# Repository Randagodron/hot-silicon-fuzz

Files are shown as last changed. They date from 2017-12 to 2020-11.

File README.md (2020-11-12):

# Hot Silicon Fuzz
Re-implementation of the FoxRox Hot Silicon Fuzz.

Full analog fuzz with bias and tone control, silicon transistors, relay true bypass, 1590A enclosure format.

Simulated with LTSpice, designed with Kicad. All simulations and CAD files are provided under creative commons CC-BY-SA 4.0

Companion article (in french) : http://blog.randagodron.eu/index.php?post/2018/02/04/DIY-audio-Hot-Silicon-Fuzz

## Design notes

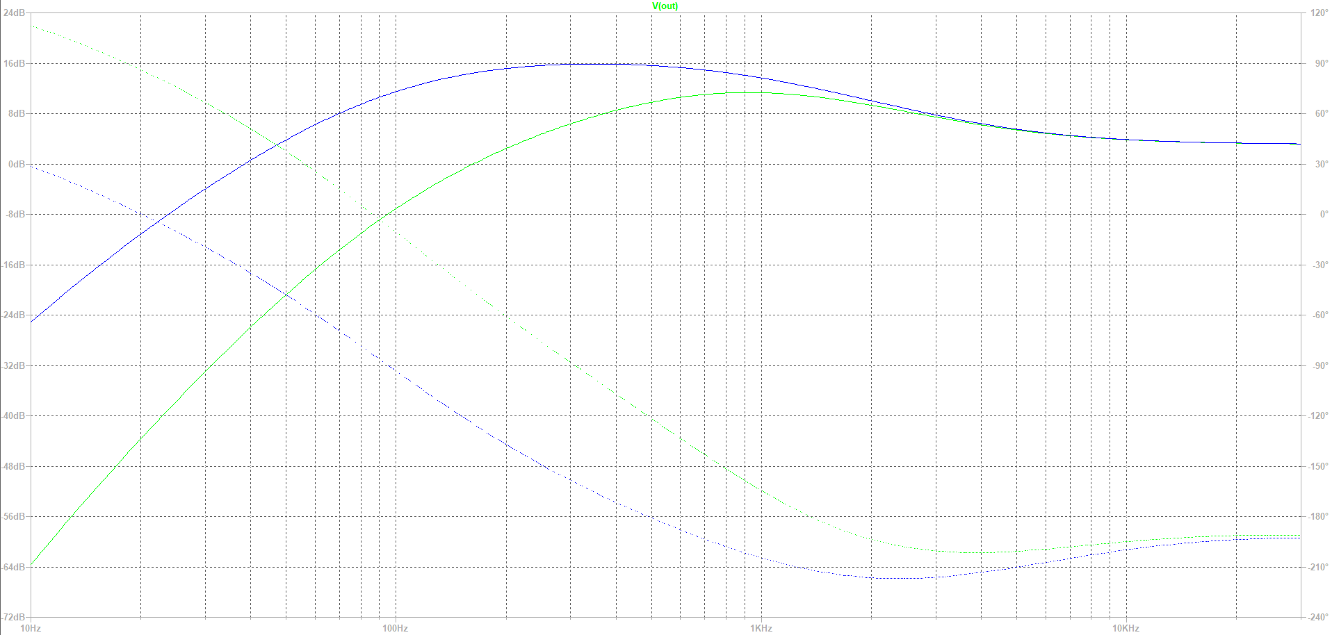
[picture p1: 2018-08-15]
export/sig_03_01_fat.PNG

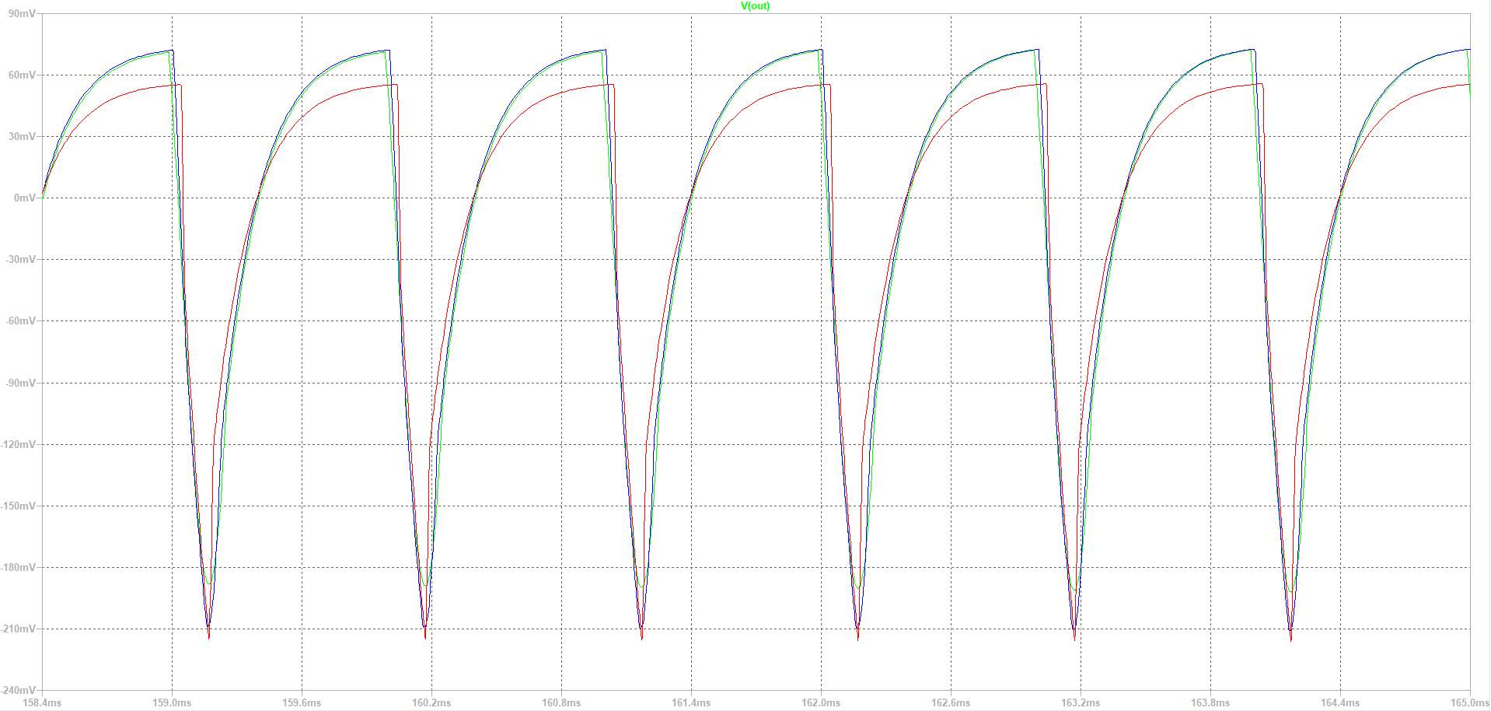
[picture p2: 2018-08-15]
export/sig_04_03.PNG

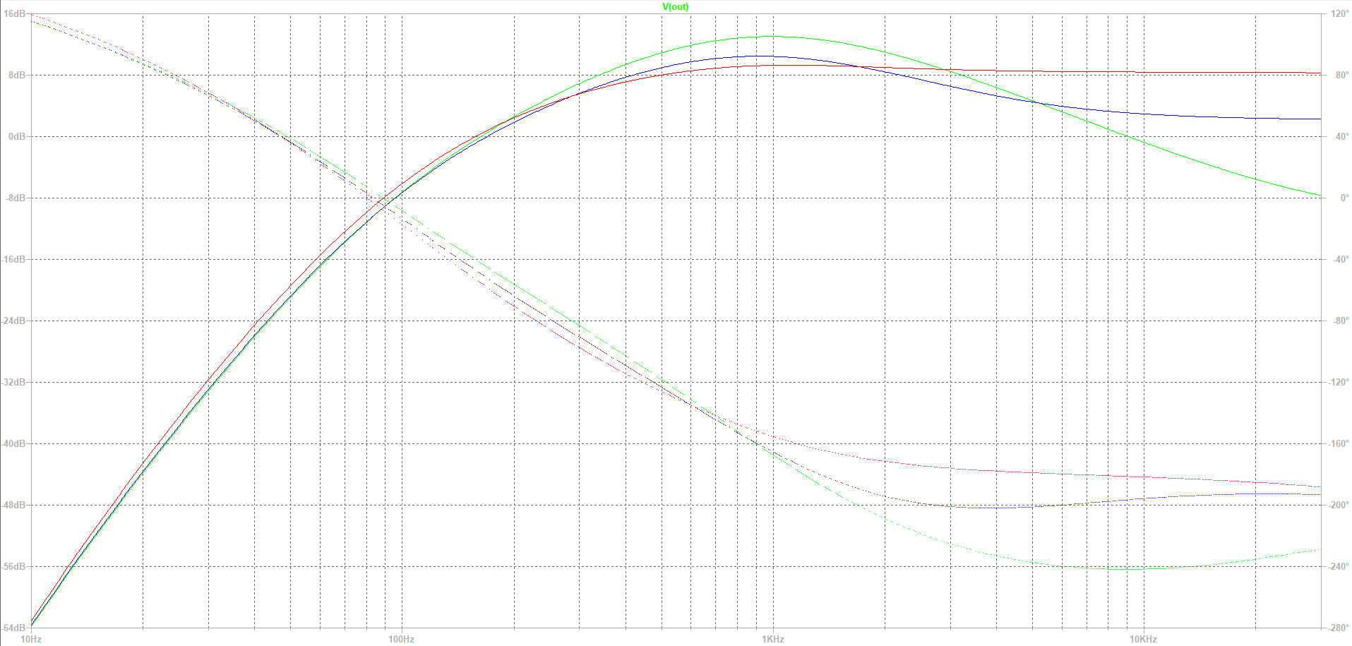
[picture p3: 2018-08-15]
export/sig_03_03_tone_0.PNG

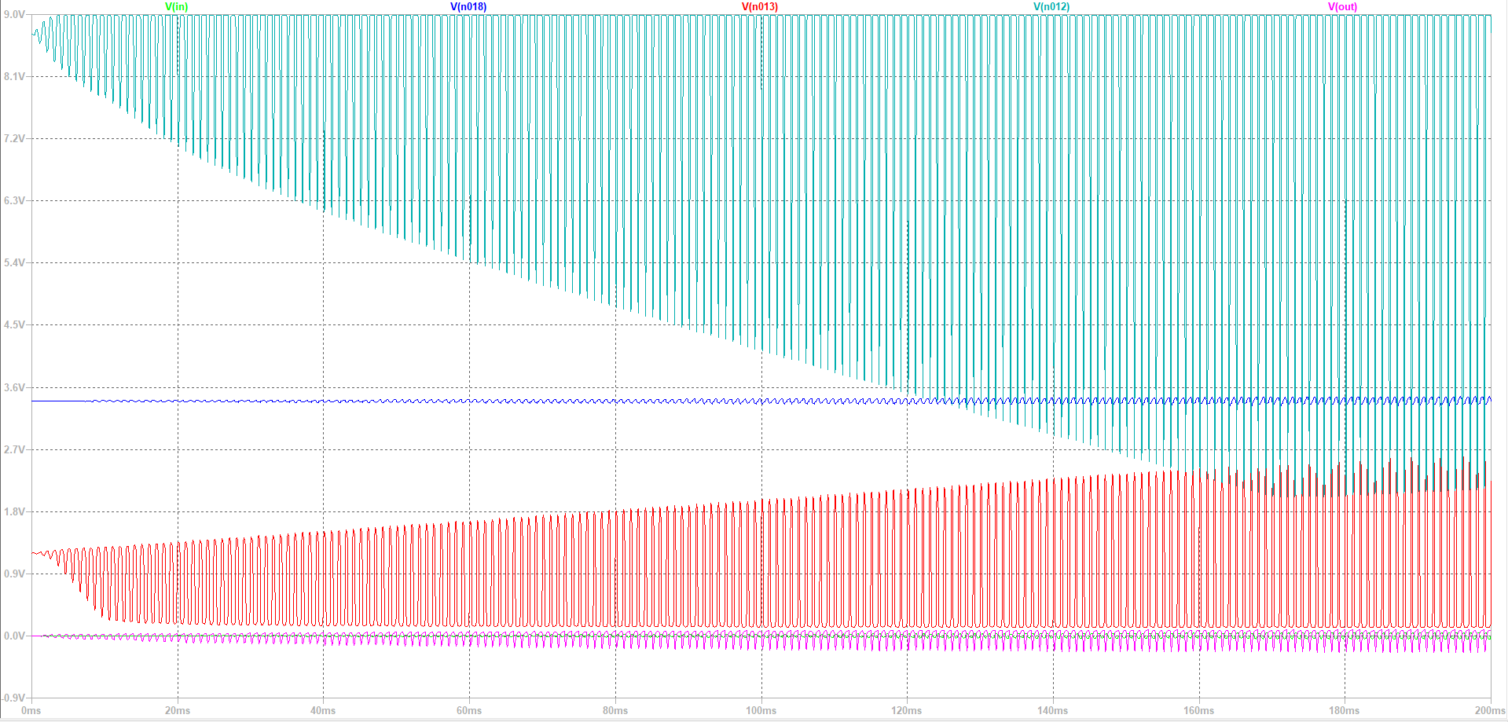
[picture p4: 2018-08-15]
export/sig_02_01_bias0.5.PNG

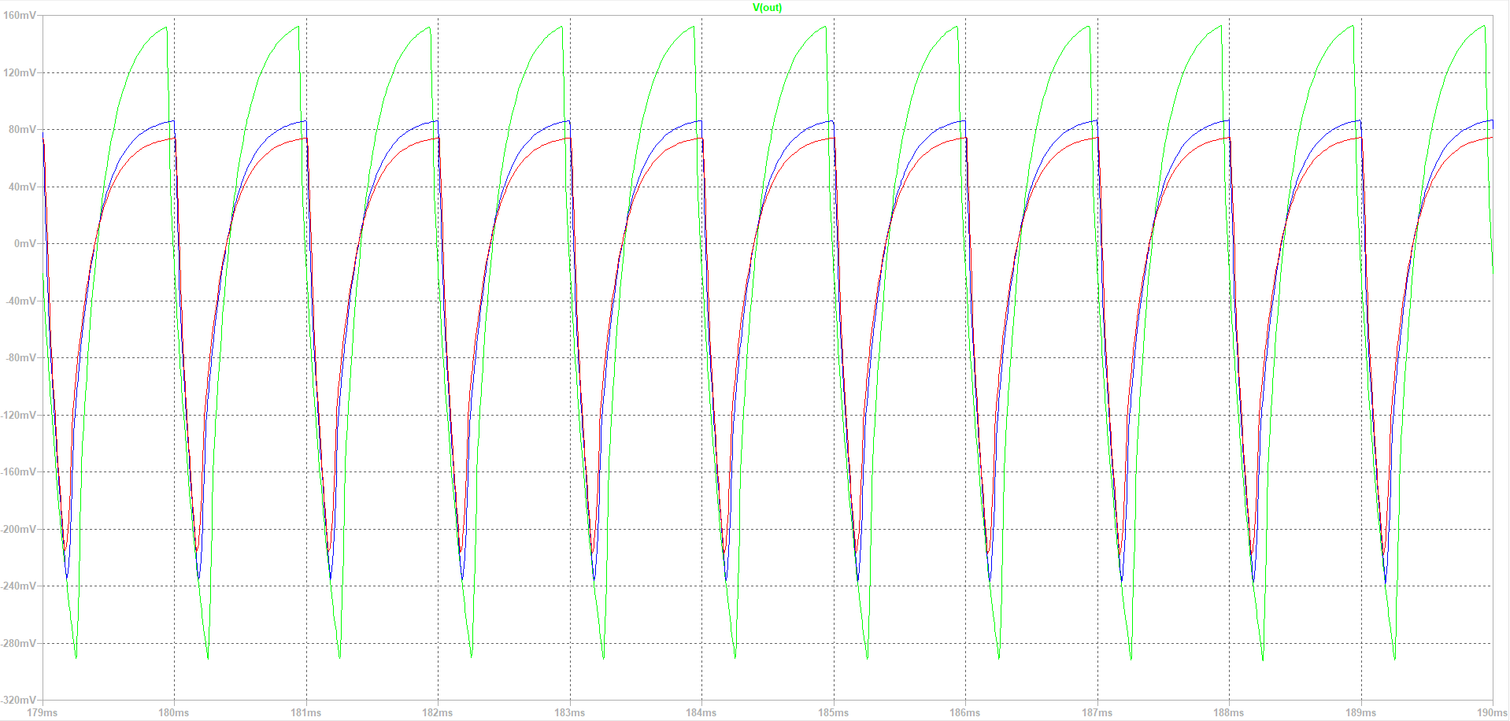
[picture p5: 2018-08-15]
export/sig_02_05.PNG

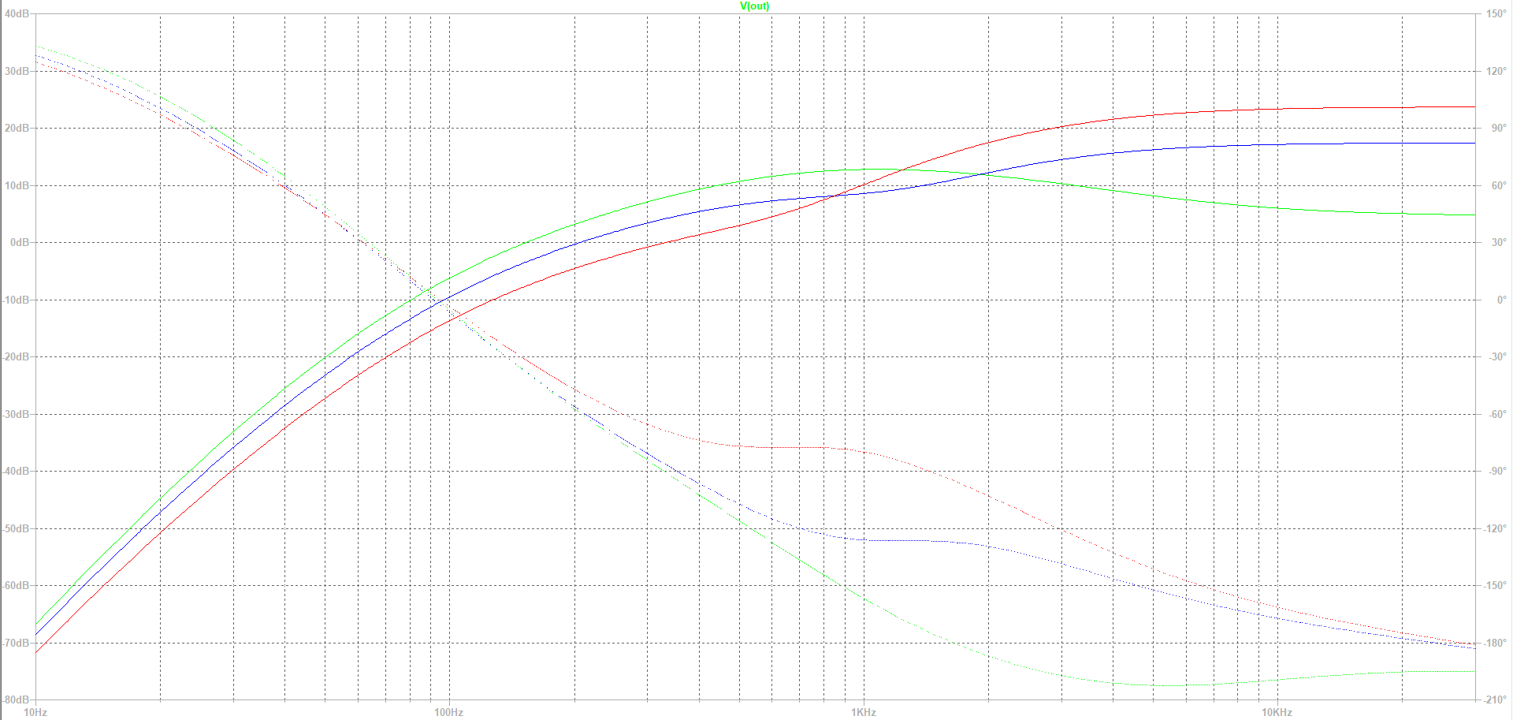
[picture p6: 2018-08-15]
export/sig_03_04_tone_1.PNG

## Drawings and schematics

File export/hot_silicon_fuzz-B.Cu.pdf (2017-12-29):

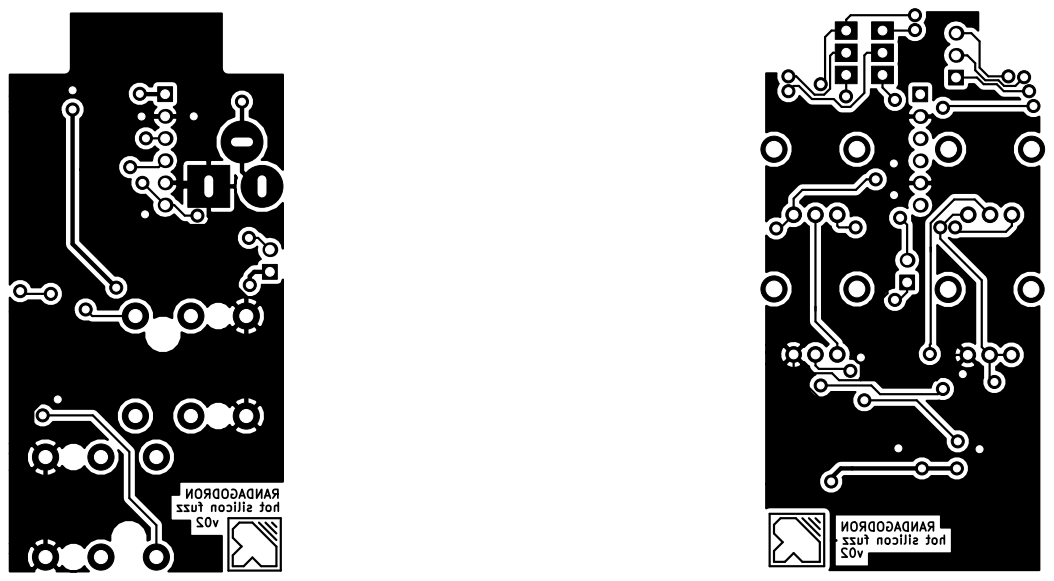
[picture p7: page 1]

v02 hot silicon fuzz v02 RANDAGODRON

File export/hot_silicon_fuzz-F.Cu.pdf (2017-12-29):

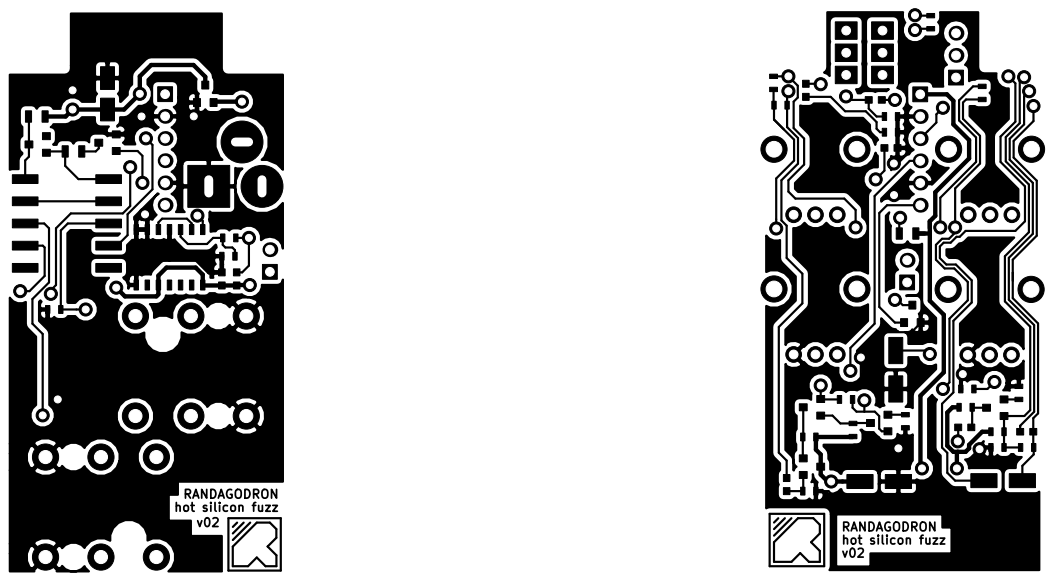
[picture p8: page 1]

v02 hot silicon fuzz RANDAGODRON

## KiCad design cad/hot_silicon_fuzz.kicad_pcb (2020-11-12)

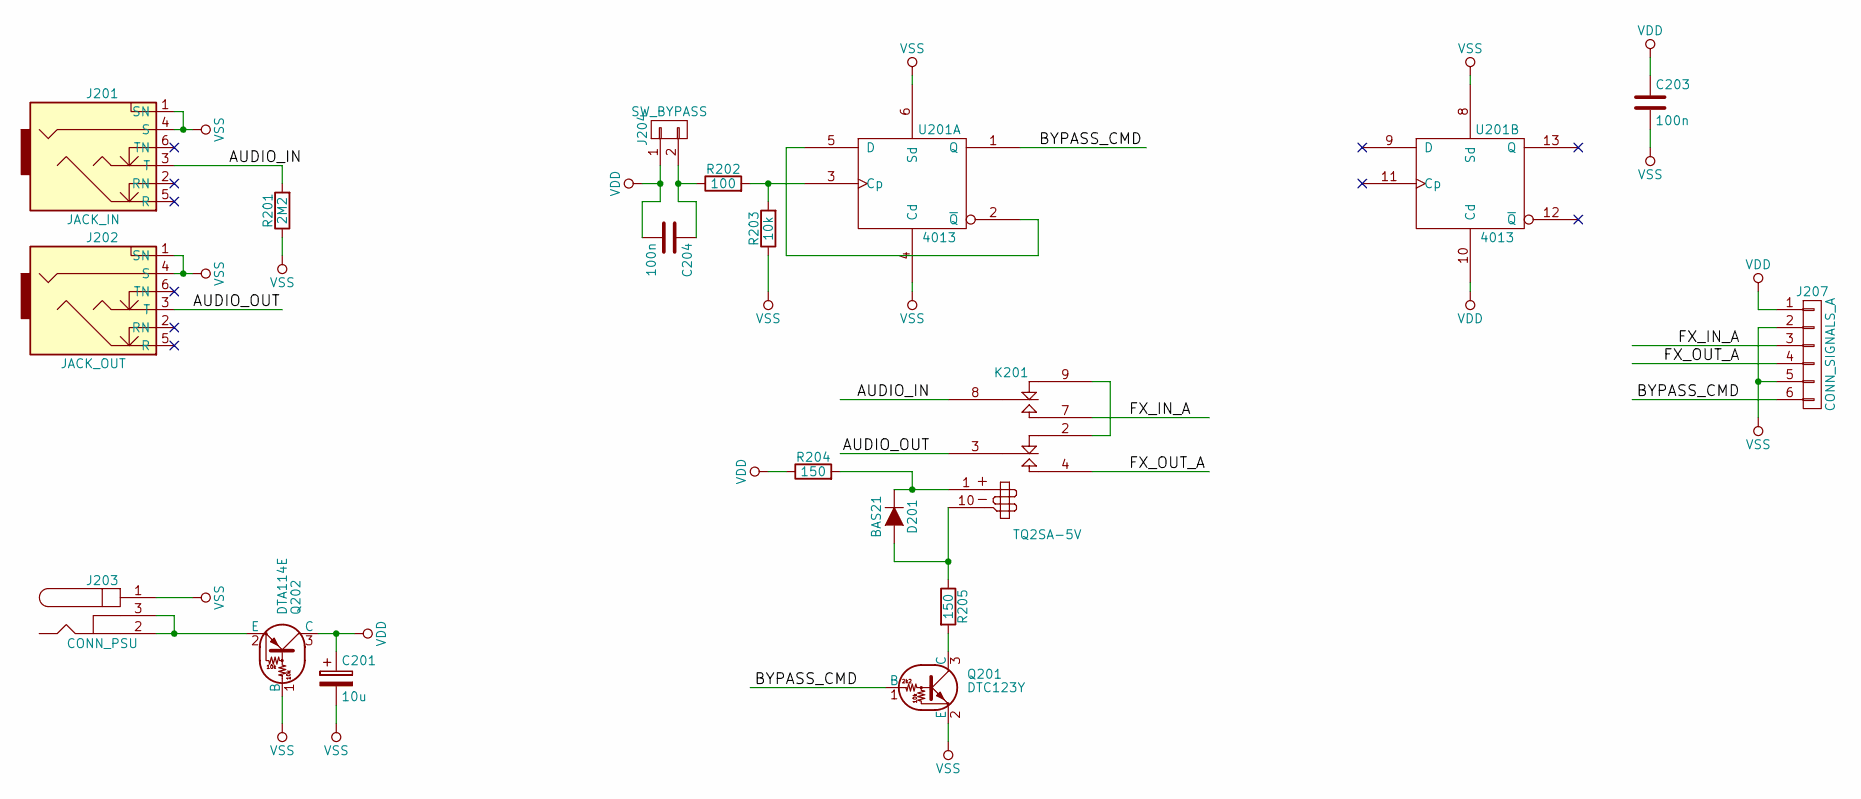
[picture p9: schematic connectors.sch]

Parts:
C201: 10u; CP_Elec_4x4.5
C203, C204: 100n; C_0603
D201: BAS21; SOT-23
J201: JACK_IN; CLIFF_FCR5005x
J202: JACK_OUT; CLIFF_FCR5005x
J203: CONN_PSU; JACK_ALIM
J204: SW_BYPASS; Pin_Header_Straight_1x02_Pitch2.54mm
J207: CONN_SIGNALS_A; Pin_Header_Straight_1x06_Pitch2.54mm
K201: TQ2SA-5V; TQ2SA
Q201: DTC123Y; SOT-23
Q202: DTA114E; SOT-23
R201: 2M2; R_0603
R202: 100; R_0603
R203: 10k; R_0603
R204, R205: 150; R_0805
U201: 4013; SOIC-14_N

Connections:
/CONNECTORS/AUDIO_IN: J201.3 (T), K201.8 (C2), R201.2
/CONNECTORS/AUDIO_OUT: J202.3 (T), K201.3 (C1)
/CONNECTORS/BYPASS_CMD: J207.6, Q201.1 (B), U201.1 (Q)
/CONNECTORS/FX_IN_A: J207.3, K201.7 (T2)
/CONNECTORS/FX_OUT_A: J207.4, K201.4 (T1)
unnamed: C204.1, J204.2, R202.1
unnamed: D201.1 (A), K201.10 (-), R205.1
unnamed: D201.3 (K), K201.1 (+), R204.2
unnamed: J203.2, J203.3, Q202.2 (E)
unnamed: K201.2 (R1), K201.9 (R2)
unnamed: Q201.3 (C), R205.2
unnamed: R202.2, R203.2, U201.3 (Cp)
unnamed: U201.2 (~Q), U201.5 (D)
VDD: C201.1, C203.1, C204.2, J204.1, J207.1, Q202.3 (C), R204.1, U201.10 (Cd), U201.14 (VDD)
VSS: C201.2, C203.2, J201.1 (SN), J201.4 (S), J202.1 (SN), J202.4 (S), J203.1, J207.2, J207.5, Q201.2 (E), Q202.1 (B), R201.1, R203.1, U201.4 (Cd), U201.6 (Sd), U201.7 (VSS), U201.8 (Sd)

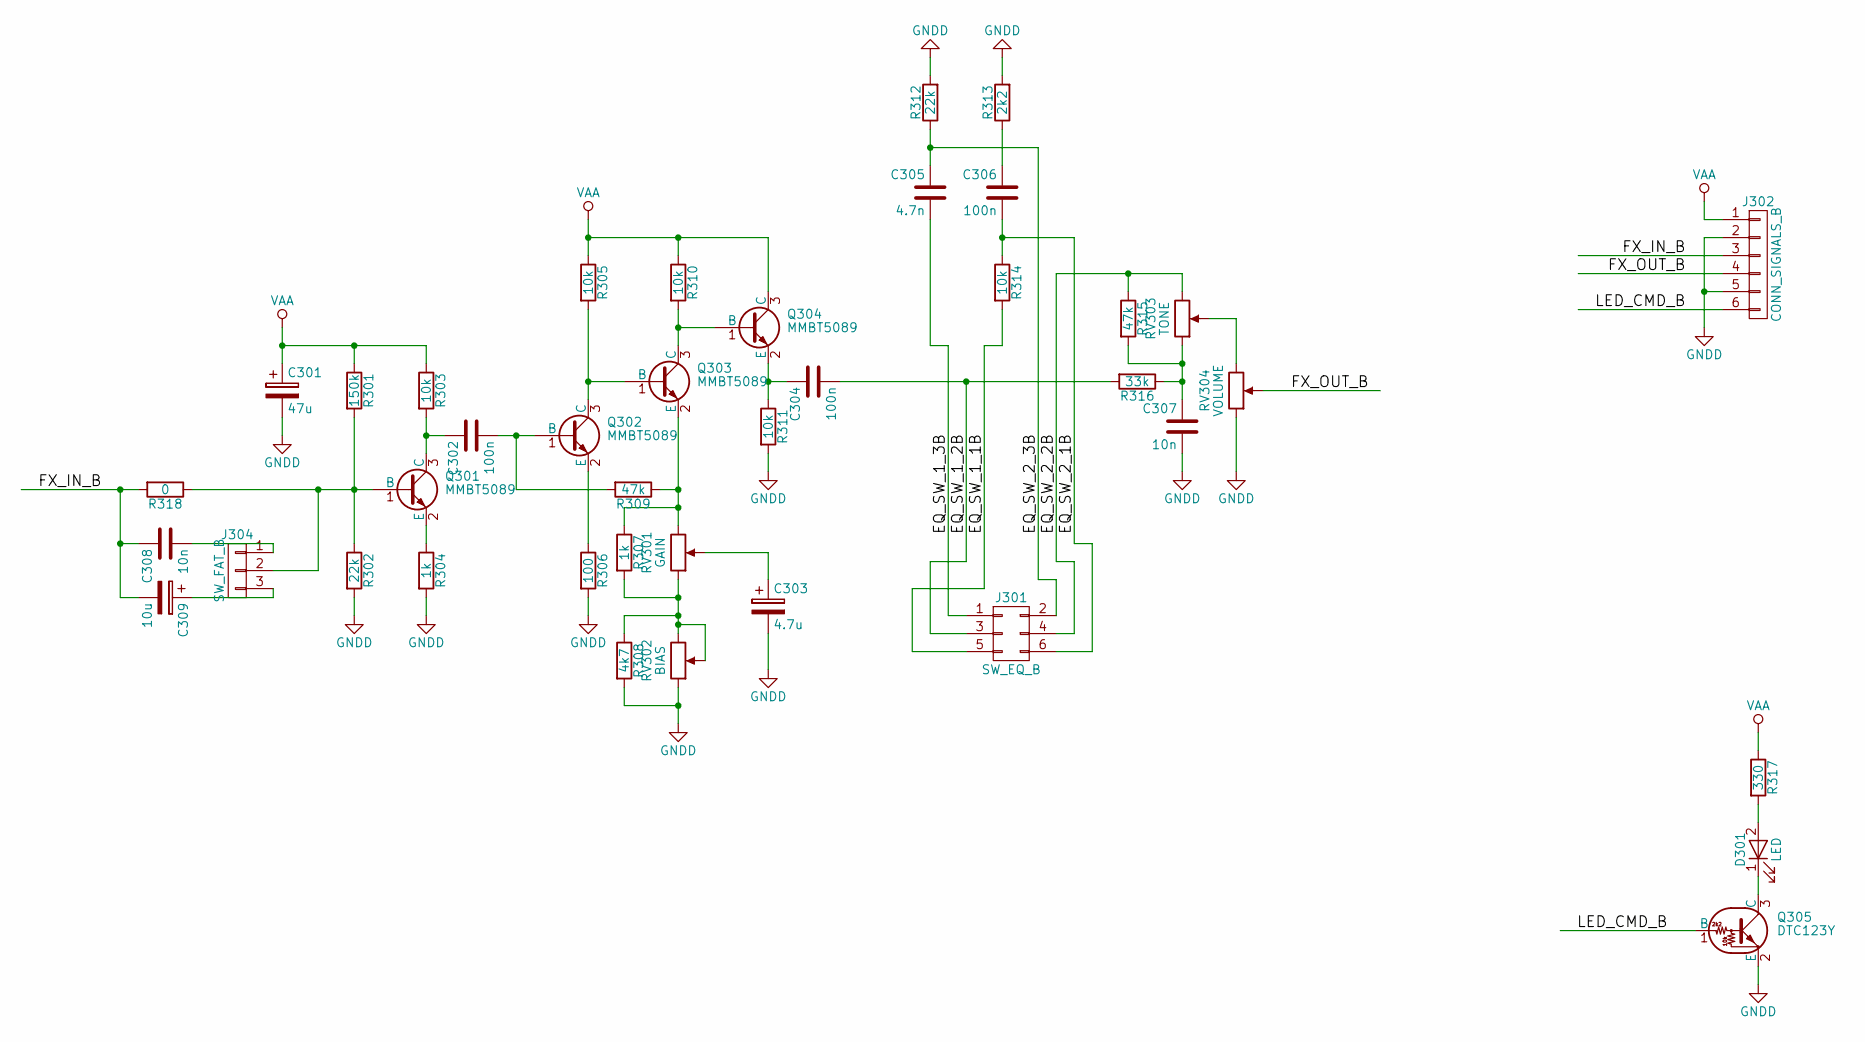
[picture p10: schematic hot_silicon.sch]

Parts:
C301: 47u; CP_Elec_5x5.3
C302, C304, C306: 100n; C_0603
C303: 4.7u; CP_Elec_5x5.3
C305: 4.7n; C_0603
C307, C308: 10n; C_0603
C309: 10u; CP_Elec_5x5.3
D301: LED; Pin_Header_Straight_1x02_Pitch2.54mm
J301: SW_EQ_B; Multicomp_sub-miniature_DPDT
J302: CONN_SIGNALS_B; Pin_Header_Straight_1x06_Pitch2.54mm
J304: SW_FAT_B; Pin_Header_Straight_1x03_Pitch2.54mm
Q301, Q302, Q303, Q304: MMBT5089; SOT-23
Q305: DTC123Y; SOT-23
R301: 150k; R_0603
R302, R312: 22k; R_0603
R303, R305, R310, R311, R314: 10k; R_0603
R304, R307: 1k; R_0603
R306: 100; R_0603
R308: 4k7; R_0603
R309, R315: 47k; R_0603
R313: 2k2; R_0603
R316: 33k; R_0603
R317: 330; R_0805
R318: 0; R_0603
RV301: GAIN; ALPS_RK09L
RV302: BIAS; ALPS_RK09L
RV303: TONE; ALPS_RK09L
RV304: VOLUME; ALPS_RK09L

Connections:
/Hot Silicon/EQ_SW_1_1B: J301.5, R314.2
/Hot Silicon/EQ_SW_1_2B: C304.2, J301.3, R316.2
/Hot Silicon/EQ_SW_1_3B: C305.2, J301.1
/Hot Silicon/EQ_SW_2_1B: C306.2, J301.6, R314.1
/Hot Silicon/EQ_SW_2_2B: J301.4, R315.1, RV303.3
/Hot Silicon/EQ_SW_2_3B: C305.1, J301.2, R312.1
/Hot Silicon/FX_IN_B: C308.1, C309.2, J302.3, R318.2
/Hot Silicon/FX_OUT_B: J302.4, RV304.2
/Hot Silicon/LED_CMD_B: J302.6, Q305.1 (B)
GNDD: C301.2, C303.2, C307.2, J302.2, J302.5, Q305.2 (E), R302.2, R304.2, R306.2, R308.2, R311.2, R312.2, R313.2, RV302.1, RV304.1
unnamed: C302.1, Q301.3 (C), R303.2
unnamed: C302.2, Q302.1 (B), R309.2
unnamed: C303.1, RV301.2
unnamed: C304.1, Q304.2 (E), R311.1
unnamed: C306.1, R313.1
unnamed: C307.1, R315.2, R316.1, RV303.1
unnamed: C308.2, J304.1
unnamed: C309.1, J304.3
unnamed: D301.1 (K), Q305.3 (C)
unnamed: D301.2 (A), R317.2
unnamed: J304.2, Q301.1 (B), R301.2, R302.1, R318.1
unnamed: Q301.2 (E), R304.1
unnamed: Q302.2 (E), R306.1
unnamed: Q302.3 (C), Q303.1 (B), R305.2
unnamed: Q303.2 (E), R307.1, R309.1, RV301.3
unnamed: Q303.3 (C), Q304.1 (B), R310.2
unnamed: R307.2, R308.1, RV301.1, RV302.2, RV302.3
unnamed: RV303.2, RV304.3
VAA: C301.1, J302.1, Q304.3 (C), R301.1, R303.1, R305.1, R310.1, R317.1

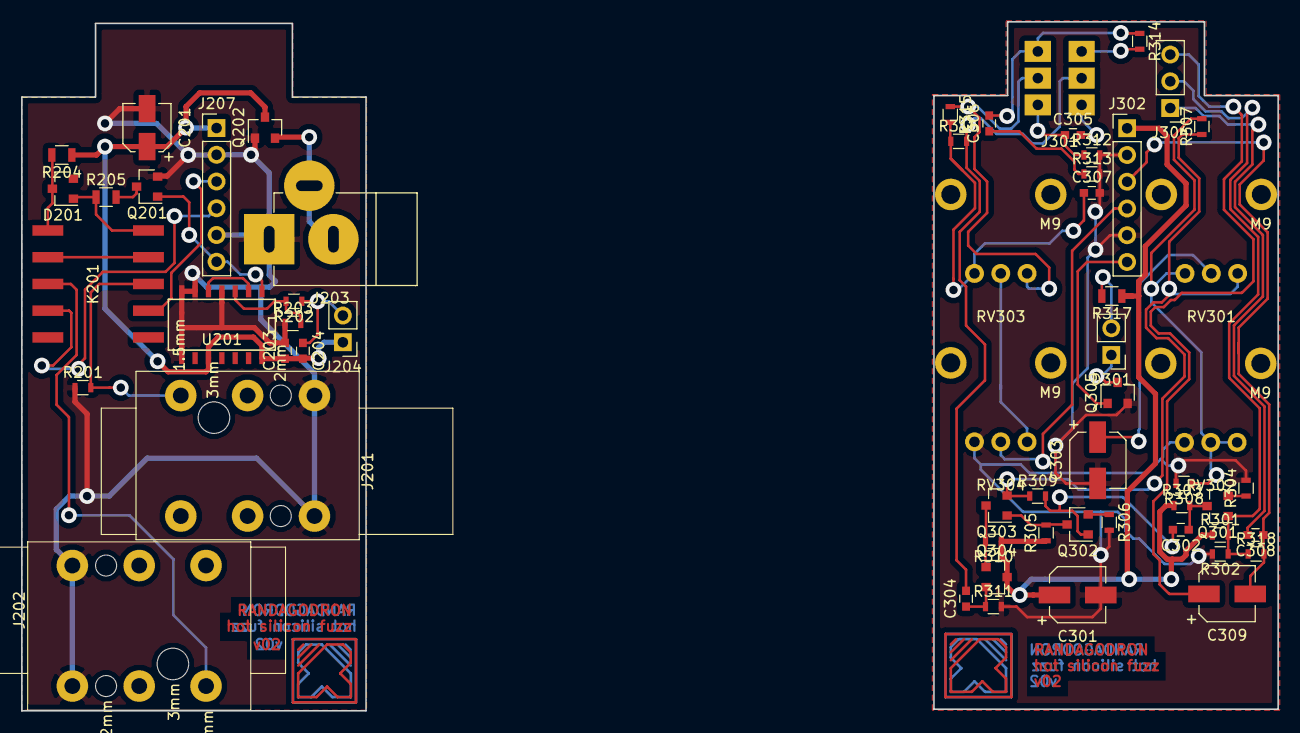
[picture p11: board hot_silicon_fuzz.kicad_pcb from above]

Board: 2 copper layers, 119.3 x 65.4 mm, 58 parts (0 on the bottom side), 44 nets.

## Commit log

2017-08-28 First commit.
    Schematic done.
    [connectors.sch, hot_silicon.sch, hot_silicon_fuzz.kicad_pcb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]
2017-08-28 Placed components. Added possibility of having switches on connector board or circuit board.
    [connectors.sch, hot_silicon.sch, hot_silicon_fuzz.kicad_pcb]
2017-09-01 Corrected pots orientation.
    Finished layout.
    [connectors.sch, hot_silicon.sch, hot_silicon_fuzz.kicad_pcb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]
2017-12-09 Exported layout.
    Done simulations.
    [hot_silicon_fuzz.kicad_pcb]
2017-12-09 Corrections on layout.
    Exported layout.
    [hot_silicon_fuzz.kicad_pcb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]
2017-12-29 Corrected layout
    [connectors.sch, hot_silicon.sch, hot_silicon_fuzz.kicad_pcb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]
2018-02-04 Added recorded samples of the pedal.
2018-08-15 Added signals plots and exported samples.
2018-12-06 Added fiducials.
    Re-exported layout.
    [hot_silicon_fuzz.kicad_pcb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]
